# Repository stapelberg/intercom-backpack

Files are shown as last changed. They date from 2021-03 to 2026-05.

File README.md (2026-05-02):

# Intercom MQTT Backpack

See https://michael.stapelberg.ch/posts/2021-03-13-smart-intercom-backpack/

## Components

### tinypico-mqtt-nuki/

ESP32 (TinyPICO) firmware that bridges the BTicino SCS bus and a Nuki Opener
to MQTT. Listens for door-station ring telegrams, drives the Nuki opener (or
the local relay), and exposes everything as MQTT topics.

#### MQTT topics

Published by the doorbell:

| Topic | Payload | Notes |
|---|---|---|
| `doorbell/status` | `online` / `offline` | retained, LWT |
| `doorbell/heartbeat` | `{"uptime_s":N,"rssi":N,"silent":bool}` | every 60 s |
| `doorbell/events/scs` | hex-encoded 7-byte SCS telegram (e.g. `a8 91 03 60 …`) | every detected frame |
| `doorbell/events/ring` | `house` or `floor` | one per ring event |
| `doorbell/silent_state` | `on` / `off` | retained, doorbell echo |
| `doorbell/debug/suppressed` | `nukiRing` / `floorRingNuki` | when silent suppressed |
| `doorbell/debug/nukiring` | `ring` | after Nuki yellow pulse |
| `doorbell/debug/doorunlock` | `doorunlock` | after relay pulse |
| `doorbell/debug/floorring` | `low` / `high` | after floor ring debounce |

Subscribed by the doorbell (set from anywhere on the LAN):

| Topic | Payload | Effect |
|---|---|---|
| `doorbell/cmd/unlock` | any | pulses the door-open relay (500 ms) |
| `doorbell/debug/cmd/ring` | any | simulates a ring (drives Nuki yellow) |
| `doorbell/silent` | `on` / `off` (retained) | suppresses Nuki auto-trigger; rings still observable on `events/ring` |

`doorbell/silent` should be published with the retained flag so the state
survives doorbell reboots:

```
mosquitto_pub -h mqtt.lan -t doorbell/silent -r -m on
```

#### Build and flash on NixOS

Pinned to esp32:esp32 2.0.17, PubSubClient 2.8, TinyPICO Helper Library 1.3.0.

One-time bootstrap (downloads the ESP32 core and the two libraries into
`~/.arduino15` and `~/Arduino`):

```bash
nix-shell -p arduino-cli --run '
  arduino-cli config init --overwrite
  arduino-cli config add board_manager.additional_urls \
    https://espressif.github.io/arduino-esp32/package_esp32_index.json
  arduino-cli core update-index
  arduino-cli core install esp32:esp32@2.0.17
  arduino-cli lib install "PubSubClient@2.8"
  arduino-cli lib install "TinyPICO Helper Library@1.3.0"
'
```

esp32 2.0.17 ships an `esptool.py` whose shebang is `#!/usr/bin/env python`
(not `python3`) and that imports `pyserial`. NixOS provides neither in the
default PATH, so build/flash needs both `arduino-cli` and a
`python3.withPackages [pyserial]` plus a one-line `python` shim:

```bash
mkdir -p ~/.local/share/arduino-pyshim
ln -sf "$(command -v python3)" ~/.local/share/arduino-pyshim/python
```

Build (verify):

```bash
nix-shell -p arduino-cli 'python3.withPackages (ps: [ps.pyserial])' --run '
  PATH=~/.local/share/arduino-pyshim:$PATH \
    arduino-cli compile --fqbn esp32:esp32:tinypico ./tinypico-mqtt-nuki
'
```

Expected: ~760 KB sketch (58 % of program flash), ~45 KB globals (13 % of
DRAM), no warnings.

Flash (TinyPICO usually shows up as `/dev/ttyUSBN` via its CP2104 USB-UART
bridge — check `ls /dev/serial/by-id/`):

```bash
nix-shell -p arduino-cli 'python3.withPackages (ps: [ps.pyserial])' --run '
  PATH=~/.local/share/arduino-pyshim:$PATH \
    arduino-cli upload -p /dev/ttyUSB0 --fqbn esp32:esp32:tinypico ./tinypico-mqtt-nuki
'
```

Access to `/dev/ttyUSB*` requires the user to be in the `dialout` group.

### qt-py-scs2uart/

Adafruit QT Py firmware that decodes SCS bus signals and forwards them as
9600-baud UART to whatever sits behind it (in this repo, the TinyPICO above).
Same arduino-cli mechanics as the tinypico build, different board package
(this one has not been re-validated on NixOS in 2026):

```bash
nix-shell -p arduino-cli --run '
  arduino-cli config add board_manager.additional_urls \
    https://www.adafruit.com/package_adafruit_index.json
  arduino-cli core update-index
  arduino-cli core install adafruit:samd
  arduino-cli compile --fqbn adafruit:samd:adafruit_qtpy_m0 ./qt-py-scs2uart
'
```

### kicad-backpack/

A board that is mounted onto the [Adafruit QT
Py](https://www.adafruit.com/product/4600) (hence “backpack”) and adds 5V/3.3V
conversion for interfacing with a BTicino intercom unit (5V).

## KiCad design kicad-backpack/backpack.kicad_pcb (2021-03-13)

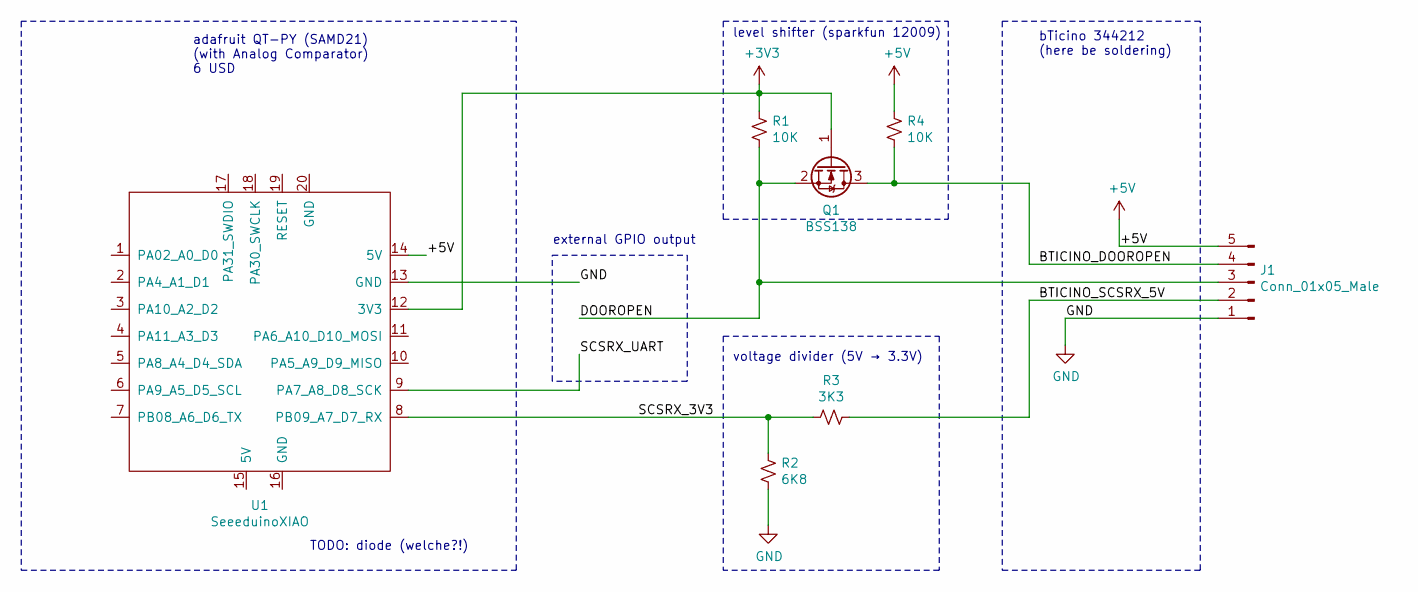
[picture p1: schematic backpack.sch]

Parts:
J1: Conn_01x05_Male; PinHeader_1x05_P2.54mm_Horizontal
Q1: BSS138; SOT-23
R1, R4: 10K; R_0603_1608Metric_Pad0.98x0.95mm_HandSolder
R2: 6K8; R_0603_1608Metric_Pad0.98x0.95mm_HandSolder
R3: 3K3; R_0603_1608Metric_Pad0.98x0.95mm_HandSolder
U1: SeeeduinoXIAO; Seeeduino XIAO-MOUDLE14P-2.54-21X17.8MM

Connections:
+3V3: Q1.1 (G), R1.1, U1.12 (3V3)
+5V: J1.5, R4.1, U1.14 (5V)
/BTICINO_DOOROPEN: J1.4, Q1.3 (D), R4.2
/BTICINO_SCSRX_5V: J1.2, R3.1
/DOOROPEN: J1.3, Q1.2 (S), R1.2
/SCSRX_3V3: R2.1, R3.2, U1.8 (PB09_A7_D7_RX)
/SCSRX_UART: U1.9 (PA7_A8_D8_SCK)
GND: J1.1, R2.2, U1.13 (GND)

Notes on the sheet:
adafruit QT-PY (SAMD21) (with Analog Comparator) 6 USD
voltage divider (5V → 3.3V)
level shifter (sparkfun 12009)
bTicino 344212 (here be soldering)
external GPIO output
TODO: diode (welche?!)

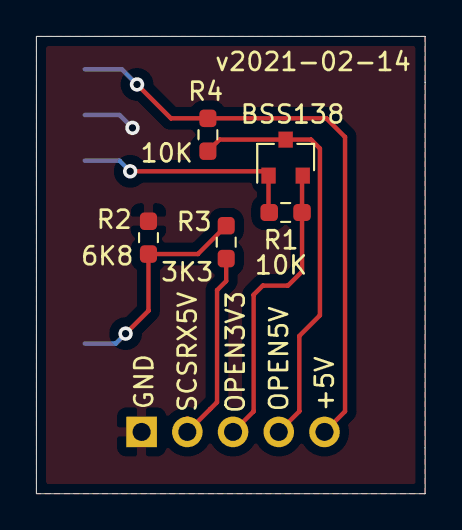
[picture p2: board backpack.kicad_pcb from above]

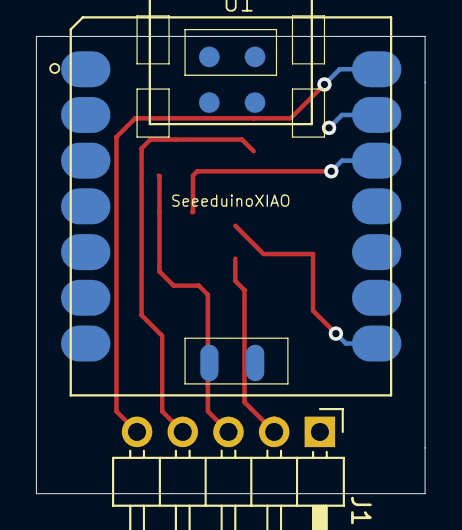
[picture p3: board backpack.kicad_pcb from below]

Board: 2 copper layers, 21.6 x 25.4 mm, 7 parts (2 on the bottom side), 7 nets.

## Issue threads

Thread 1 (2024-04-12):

ESP Biticino scs bus

MattWestb, 2024-04-12:
Have you thinking porting the code to ESPHome ?
I have one device and 32 neighbors and like getting it easy integrated in HA but dont have the code experience for do it only the hardware hacking im good on (like Zigbee hardware and so on).
Thanks in advance.

MW

stapelberg, 2024-04-12:
I have no plans to port this code to ESPhome.

If you don’t have the experience, I suggest finding a local makerspace, hackerspace or fablab. The community there will be able to help you with such electronics projects.

MattWestb, 2024-04-12:
Servus Michael.

Thanks for replaying. I continue looking around and see if i can finding some usebal code then you have getting all the hardware in place (I think i have taken the power on the cap if its is 5V and not on the small pins on one IC).

Mvh Mattias W

Closed 2024-04-12.

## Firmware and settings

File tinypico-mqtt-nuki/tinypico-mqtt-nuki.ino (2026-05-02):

#include <PubSubClient.h>
#include <TinyPICO.h>
#include <WiFi.h>
#include <driver/adc.h>
#include <driver/dac.h>

#include "scsfilter.h"

#define GPIO_DOOR_OPEN 27
#define GPIO_NUKI_YELLOW 14
#define GPIO_NUKI_BLUE 15
#define GPIO_FLOOR_RING 4

void nukiRing(void *pvParameters);

WiFiClient wificlient;
PubSubClient client(wificlient);

// PubSubClient is not thread-safe. All client.publish/connect/loop calls go
// through this mutex; publishers from other tasks use mqttPublish below.
static SemaphoreHandle_t xMqttMutex = NULL;

static bool mqttPublish(const char *topic, const char *payload,
                        bool retained = false) {
  if (xSemaphoreTake(xMqttMutex, pdMS_TO_TICKS(200)) != pdTRUE) return false;
  bool ok = client.publish(topic, payload, retained);
  xSemaphoreGive(xMqttMutex);
  return ok;
}

// silentMode suppresses the nuki opener auto-trigger from ring events.
// Toggled via retained MQTT topic doorbell/silent ("on"/"off").
static volatile bool silentMode = false;

// TODO: give this a constructor or something
scsfilter sf;

static bool ignore_scs_telegrams = false;
static uint8_t ignore_scs_checksum;
static TimerHandle_t xQuietTimer;

void scsquietnow(void *pvParameters) {
  ignore_scs_telegrams = false;
  Serial.println("timer fire, messages okay again");
  xTimerDelete(xQuietTimer, 10);
  xQuietTimer = NULL;
}

void taskscsprocess(void *pvParameters) {
  for (;;) {
    if (Serial2.available() == 0) {
      vTaskDelay(pdMS_TO_TICKS(10));
      continue;
    }

    byte incomingByte = Serial2.read();
    Serial.printf("[core %d] SCSRX: ", xPortGetCoreID());
    Serial.println(incomingByte, HEX);

    // We store the checksum of telegrams to ignore, so that different
    // messages are not accidentally ignored by the quiet timer.
    //
    // This can happen when e.g. the mailman rings the neighbor first, and then
    // my doorbell: the ring signal for my doorbell was ignored while the bus
    // was still active from delivering the neighbor ring signal.
    const bool ignore_this_telegram = ignore_scs_telegrams;
    const uint8_t ignore_this_telegram_checksum = ignore_scs_checksum;

    if (xQuietTimer != NULL) {
      xTimerReset(xQuietTimer, 10);
    }

    // feed this byte into the SCS decoder:
    sf_WriteByte(&sf, incomingByte);

    if (!sf_completeAndValid(&sf)) {
      continue;
    }

    const uint8_t checksum = sf.tbuf[5];
    Serial.printf("complete SCS telegram detected, checksum %x\n", checksum);

    if (ignore_this_telegram && ignore_this_telegram_checksum == checksum) {
      Serial.println("ignoring retransmission");
      continue;
    }

    {
      // Ignore the SCS bus retransmissions by waiting until the bus quiets
      // down: this timer gets restarted on every received byte.
      ignore_scs_telegrams = true;
      ignore_scs_checksum = checksum;
      xQuietTimer =
          xTimerCreate("scsquiet", // human readable text name for debugging
                       pdMS_TO_TICKS(50), // xTimerPeriod (in ticks)
                       pdFALSE,           // uxAutoReload (or one-shot)
                       NULL,              // timer id
                       scsquietnow);      // callback function
      if (xQuietTimer != NULL) {
        xTimerStart(xQuietTimer, 0);
        Serial.println("timer start");
      }
    }

    // Publish an MQTT message for each SCS telegram, hex-encoded so bytes
    // >=0x80 survive UTF-8-decoding MQTT subscribers (mosquitto_sub -v etc).
    char hex[3 * telegramLen];
    snprintf(hex, sizeof(hex),
             "%02x %02x %02x %02x %02x %02x %02x",
             sf.tbuf[0], sf.tbuf[1], sf.tbuf[2], sf.tbuf[3],
             sf.tbuf[4], sf.tbuf[5], sf.tbuf[6]);
    mqttPublish("doorbell/events/scs", hex);
    Serial.println("mqtt publish");

    if (sf_ringForApartment(&sf) == 3) {
      mqttPublish("doorbell/events/ring", "house");
      Serial.println("ring detected, triggering nuki opener");
      xTaskCreatePinnedToCore(nukiRing, "nukiRing", 4096, NULL, 1, NULL,
                              PRO_CPU_NUM);
    }
  }
}

// --------------------------------------------------------------------------------

void connectToWiFi(void) {
  Serial.println("WiFi: configuring");
  WiFi.mode(WIFI_STA);
  // required to set hostname properly:
  // https://github.com/espressif/arduino-esp32/issues/3438#issuecomment-721428310
  WiFi.config(INADDR_NONE, INADDR_NONE, INADDR_NONE, INADDR_NONE);
  WiFi.setHostname("doorbelltp");
  WiFi.begin("secret", "secret");
  while (WiFi.status() != WL_CONNECTED) {
    Serial.println("WiFi: connecting...");
    delay(100);
  }
  Serial.print("WiFi: connected: mac=");
  Serial.print(WiFi.macAddress());
  Serial.print(" ip=");
  Serial.print(WiFi.localIP());
  Serial.println("");
}

// --------------------------------------------------------------------------------

void nukiRing(void *pvParameters) {
  Serial.printf("[core %d] nukiRing\n", xPortGetCoreID());
  if (silentMode) {
    mqttPublish("doorbell/debug/suppressed", "nukiRing");
    vTaskDelete(NULL);
    return;
  }
  digitalWrite(GPIO_NUKI_YELLOW, HIGH);
  vTaskDelay(pdMS_TO_TICKS(1000));
  digitalWrite(GPIO_NUKI_YELLOW, LOW);
  mqttPublish("doorbell/debug/nukiring", "ring");
  vTaskDelete(NULL);
}

void doorUnlock(void *pvParameters) {
  Serial.printf("[core %d] doorUnlock\n", xPortGetCoreID());
  digitalWrite(GPIO_DOOR_OPEN, LOW);
  vTaskDelay(pdMS_TO_TICKS(500));
  digitalWrite(GPIO_DOOR_OPEN, HIGH);
  mqttPublish("doorbell/debug/doorunlock", "doorunlock");
  vTaskDelete(NULL);
}

SemaphoreHandle_t xNukiOpenSemaphore = NULL;

// IRAM_ATTR: all interrupt service routines must go into the internal SRAM:
// https://docs.espressif.com/projects/esp-idf/en/latest/esp32/api-guides/general-notes.html#iram-instruction-ram
void IRAM_ATTR nukiOpen() { xSemaphoreGiveFromISR(xNukiOpenSemaphore, NULL); }

// setupnuki0 runs the wakeup loop. It is pinned to PRO_CPU so the handler
// task is on the same core as the original interrupt-handling design.
void setupnuki0(void *pvParameters) {
  for (;;) {
    if (xSemaphoreTake(xNukiOpenSemaphore, portMAX_DELAY) != pdTRUE) {
      continue;
    }

    // TODO: where do these come from? unclear.
    if (digitalRead(GPIO_NUKI_BLUE) != LOW) {
      Serial.printf("ignoring spurious nukiOpen\n");
      continue;
    }

    xTaskCreatePinnedToCore(doorUnlock, "doorUnlock", 4096, NULL, 1, NULL,
                            PRO_CPU_NUM);
  }
}

void setupnuki(void) {
  xNukiOpenSemaphore = xSemaphoreCreateBinary();

  // pin GPIO_NUKI_YELLOW: connected to nuki opener yellow cable (RING)
  pinMode(GPIO_NUKI_YELLOW, OUTPUT);
  digitalWrite(GPIO_NUKI_YELLOW, LOW);

  // pin GPIO_NUKI_BLUE: connected to nuki opener blue cable (OPEN)
  pinMode(GPIO_NUKI_BLUE, INPUT_PULLUP);
  // attachInterrupt must run before the loop tasks start: arduino-esp32 2.x
  // crashes (LoadProhibited in esp_intr_get_cpu) if two tasks race to call
  // attachInterrupt for the first time. setup() serializes it.
  attachInterrupt(GPIO_NUKI_BLUE, nukiOpen, FALLING);
  xTaskCreatePinnedToCore(setupnuki0, "setupnuki0", 4096, NULL, 1, NULL,
                          PRO_CPU_NUM);
}

// --------------------------------------------------------------------------------

void floorRingNuki(void *pvParameters) {
  Serial.printf("[core %d] floorRing\n", xPortGetCoreID());
  mqttPublish("doorbell/events/ring", "floor");
  if (silentMode) {
    mqttPublish("doorbell/debug/suppressed", "floorRingNuki");
    vTaskDelete(NULL);
    return;
  }
  const byte state = digitalRead(GPIO_FLOOR_RING);
  digitalWrite(GPIO_NUKI_YELLOW, HIGH);
  vTaskDelay(pdMS_TO_TICKS(1000));
  digitalWrite(GPIO_NUKI_YELLOW, LOW);
  mqttPublish("doorbell/debug/floorring", state == LOW ? "low" : "high");
  vTaskDelete(NULL);
}

SemaphoreHandle_t xFloorOpenSemaphore = NULL;

// IRAM_ATTR: all interrupt service routines must go into the internal SRAM:
// https://docs.espressif.com/projects/esp-idf/en/latest/esp32/api-guides/general-notes.html#iram-instruction-ram
void IRAM_ATTR floorRing() { xSemaphoreGiveFromISR(xFloorOpenSemaphore, NULL); }

static byte floorRingState = LOW;
static unsigned long lastFloorRing;

// setupfloor0 runs the wakeup loop. attachInterrupt was already called from
// setupfloor() on the main task to avoid the arduino-esp32 2.x race.
void setupfloor0(void *pvParameters) {
  for (;;) {
    if (xSemaphoreTake(xFloorOpenSemaphore, portMAX_DELAY) != pdTRUE) {
      continue;
    }
    if (floorRingState == LOW && (millis() - lastFloorRing) < 1000) {
      continue; // debounce by waiting it out
    }

    const byte state = digitalRead(GPIO_FLOOR_RING);
    Serial.printf("GPIO_FLOOR_RING was %s\n",
                  floorRingState == LOW ? "low" : "high");
    Serial.printf("GPIO_FLOOR_RING is %s\n", state == LOW ? "low" : "high");
    Serial.printf("\n");
    if (floorRingState == LOW && state == HIGH) {
      // debounce: wait if HIGH after 100ms still
      vTaskDelay(pdMS_TO_TICKS(100));
      const byte debouncedstate = digitalRead(GPIO_FLOOR_RING);
      Serial.printf("debouncedstate is %s\n",
                    debouncedstate == LOW ? "low" : "high");
      if (debouncedstate != HIGH) {
        continue; // too short a press, or spurious
      }
      xTaskCreatePinnedToCore(floorRingNuki, "floorRingNuki", 4096, NULL, 1,
                              NULL, PRO_CPU_NUM);
      lastFloorRing = millis();
    }
    floorRingState = state;
  }
}

void setupfloor(void) {
  xFloorOpenSemaphore = xSemaphoreCreateBinary();

  // pin GPIO_FLOOR_RING: connected to floor ring signal
  pinMode(GPIO_FLOOR_RING, INPUT_PULLDOWN);
  attachInterrupt(GPIO_FLOOR_RING, floorRing, RISING);
  xTaskCreatePinnedToCore(setupfloor0, "setupfloor0", 4096, NULL, 1, NULL,
                          PRO_CPU_NUM);
}

// --------------------------------------------------------------------------------

void callback(char *topic, byte *payload, unsigned int length) {
  Serial.print("Message arrived [");
  Serial.print(topic);
  Serial.print("] ");
  for (int i = 0; i < length; i++) {
    Serial.print((char)payload[i]);
  }
  Serial.println();

  if (strcmp(topic, "doorbell/cmd/unlock") == 0) {
    xTaskCreatePinnedToCore(doorUnlock, "doorUnlock", 4096, NULL, 1, NULL,
                            PRO_CPU_NUM);
  }

  if (strcmp(topic, "doorbell/debug/cmd/ring") == 0) {
    xTaskCreatePinnedToCore(nukiRing, "nukiRing", 4096, NULL, 1, NULL,
                            PRO_CPU_NUM);
  }

  if (strcmp(topic, "doorbell/silent") == 0) {
    // payload is not NUL-terminated; compare with length.
    bool newMode =
        (length == 2 && payload[0] == 'o' && payload[1] == 'n');
    silentMode = newMode;
    Serial.printf("silentMode = %d\n", newMode ? 1 : 0);
    // We are inside client.loop(), which taskmqtt called while holding
    // xMqttMutex — use the raw publish (not mqttPublish) to avoid the
    // wrapper's redundant take-with-timeout.
    client.publish("doorbell/silent_state", newMode ? "on" : "off",
                   /* retained */ true);
  }
}

void taskmqtt(void *pvParameters) {
  for (;;) {
    xSemaphoreTake(xMqttMutex, portMAX_DELAY);
    if (!client.connected()) {
      // TODO: do we need a timeout here? does client.connect only block the
      // taskmqtt FreeRTOS task, or all FreeRTOS tasks on this core?
      client.connect("doorbelltp",     // clientid
                     "doorbell/status", // willTopic
                     0,                 // willQos
                     true,              // willRetain
                     "offline");        // willMessage
      client.publish("doorbell/status", "online", /* retained */ true);
      client.subscribe("doorbell/cmd/unlock");
      client.subscribe("doorbell/debug/cmd/ring");
      client.subscribe("doorbell/silent");
    }

    // Poll PubSubClient for new messages and invoke the callback.
    // Should be called as infrequent as one is willing to delay
    // reacting to MQTT messages.
    // Should not be called too frequently to avoid strain on
    // the network hardware:
    // https://github.com/knolleary/pubsubclient/issues/756#issuecomment-654335096
    client.loop();
    xSemaphoreGive(xMqttMutex);
    vTaskDelay(pdMS_TO_TICKS(100));
  }
}

// --------------------------------------------------------------------------------

void taskalive(void *pvParameters) {
  for (;;) {
    char buf[96];
    snprintf(buf, sizeof(buf),
             "{\"uptime_s\":%lu,\"rssi\":%d,\"silent\":%s}",
             (unsigned long)(millis() / 1000),
             (int)WiFi.RSSI(),
             silentMode ? "true" : "false");
    mqttPublish("doorbell/heartbeat", buf);
    vTaskDelay(pdMS_TO_TICKS(60000));
  }
}

// --------------------------------------------------------------------------------

void taskreconnect(void *pvParameters) {
  for (;;) {
    if (WiFi.status() != WL_CONNECTED) {
      Serial.printf("reconnecting to WiFi\n");
      connectToWiFi();
    }
    vTaskDelay(pdMS_TO_TICKS(60 * 1000));
  }
}

// --------------------------------------------------------------------------------

TinyPICO tp = TinyPICO();

void setup() {
  // Turn on Power LED:
  tp.DotStar_SetPixelColor(255, 128, 0);

  memset(&sf, '\0', sizeof(scsfilter));

  Serial.begin(115200);
  delay(1000);

  connectToWiFi();

  xMqttMutex = xSemaphoreCreateMutex();

  client.setServer("mqtt.lan", 1883);
  client.setCallback(callback);

  pinMode(GPIO_DOOR_OPEN, OUTPUT);
  digitalWrite(GPIO_DOOR_OPEN, HIGH);

  setupnuki();
  setupfloor();

  // setup UART2 (U2UXD) on GPIO pin 25 (RX)
  Serial2.begin(9600, SERIAL_8N1, 25, 26);

  // https://docs.espressif.com/projects/esp-idf/en/latest/esp32/api-guides/freertos-smp.html#scheduling
  // CPU 0 (PRO_CPU): protocol cpu
  // CPU 1 (APP_CPU): application cpu
  //
  // arduino-esp32 defaults to using APP_CPU for loop() and WiFi onEvent
  // callbacks. We leave loop() empty and use APP_CPU entirely for SCS ADC
  // conversion. Disable the IDLE-task watchdog on both cores: arduino-esp32
  // 2.x enforces it by default, and our PRO_CPU-pinned MQTT task can spend
  // multiple seconds inside PubSubClient::connect() during reconnects,
  // starving IDLE0 and tripping the watchdog.
  disableCore0WDT();
  disableCore1WDT();

  // Stack sizes were 2048 in the arduino-esp32 1.0.4 era, but 2.0.17's
  // runtime (attachInterrupt, WiFi/MQTT call paths) uses considerably
  // more stack — 2048 trips the stack canary in setupfloor0 within
  // seconds of WiFi connect. 4096 is the safe minimum; taskmqtt gets
  // 8192 since callback() runs on its stack during client.loop().
  xTaskCreatePinnedToCore(taskscsprocess, "SCS", 4096, NULL, 1, NULL,
                          PRO_CPU_NUM);

  xTaskCreatePinnedToCore(taskmqtt, "MQTT", 8192, NULL, 1, NULL, PRO_CPU_NUM);

  xTaskCreatePinnedToCore(taskalive, "Alive", 4096, NULL, 1, NULL, PRO_CPU_NUM);

  xTaskCreatePinnedToCore(taskreconnect, "reconnect", 4096, NULL, 1, NULL,
                          PRO_CPU_NUM);
}

// Arduino loop function unused in favor of FreeRTOS tasks.
// The ESP32 Arduino Board Support Package runs loop in a FreeRTOS task itself.
void loop() { vTaskDelay(pdMS_TO_TICKS(1000)); }

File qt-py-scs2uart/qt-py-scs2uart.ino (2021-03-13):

void setupADC();

void setup() {

  // SCSRX (from level shifter):
  pinMode(7, INPUT);

  // SCSRXUART (modified signal)
  pinMode(8, OUTPUT);
  digitalWrite(8, HIGH);

  setupADC();

  // turn off the NeoPixel for low power usage
  digitalWrite(12, LOW);
}

// Atmel AT11480: Analog Comparator Application Examples (18 pages)
// http://ww1.microchip.com/downloads/en/DeviceDoc/Atmel-42473-Analog-Comparator-Application-Examples_UserGuide_AT11480.pdf
// https://github.com/avrxml/asf/blob/master/sam0/applications/ac_examples/main.c

void setupADC() {
  PM->APBCMASK.reg |= PM_APBCMASK_AC;

  GCLK->CLKCTRL.reg =
      GCLK_CLKCTRL_CLKEN | GCLK_CLKCTRL_GEN_GCLK0 | GCLK_CLKCTRL_ID_AC_ANA;
  while (GCLK->STATUS.bit.SYNCBUSY)
    ;

  GCLK->CLKCTRL.reg =
      GCLK_CLKCTRL_CLKEN | GCLK_CLKCTRL_GEN_GCLK0 | GCLK_CLKCTRL_ID_AC_DIG;
  while (GCLK->STATUS.bit.SYNCBUSY)
    ;

  // Analog Comparator unterstützt als analog inputs nur:
  // - PA04: A2 (linke seite)
  // - PA05: A3 (linke seite)
  // - PA06: TX_A6 (linke seite)
  // - PA07: RX_A7 (rechte seite)

  // PA07, i.e. RX_A7, analog input
  {
    // Disable digital pin circuitry
    // gpio_set_pin_direction(PA05, GPIO_DIRECTION_OFF);
    PORT->Group[PORTA].DIRCLR.reg = (1 << 7); // turn off
    PORT->Group[PORTA].WRCONFIG.reg = PORT_WRCONFIG_WRPINCFG | (1 << 7);

    // gpio_set_pin_function(PA05, PINMUX_PA05B_AC_AIN1);
    // _gpio_set_pin_function(PA05, PINMUX_PA05B_AC_AIN1);
    PORT->Group[PORTA].PINCFG[7].bit.PMUXEN = 1;
    PORT->Group[PORTA].PMUX[7 >> 1].reg |= PORT_PMUX_PMUXO_B;
  }

  // Analog Comparator
  // ///////////////////////////////////////////////////////////////////////

  AC->COMPCTRL[0].reg =
      AC_COMPCTRL_HYST |        // Enable input hysteresis
      AC_COMPCTRL_OUT_OFF |     // Enable comparator output in asynchronous mode
      AC_COMPCTRL_MUXPOS_PIN3 | // Set the positive input multiplexer to AIN[3]
      AC_COMPCTRL_MUXNEG_VSCALE | // Set the negative input multiplexer to the
                                  // voltage scaler
      AC_COMPCTRL_SPEED_HIGH |    // Place the comparator into high speed mode
      AC_COMPCTRL_INTSEL_TOGGLE;
  while (AC->STATUSB.bit.SYNCBUSY)
    ; // Wait for synchronization

  AC->SCALER[0].reg = AC_SCALER_VALUE(
      39); // Set the negative input voltage scale to 2V
           // Vscale = Vdd * (VALUE + 1) / 64 = 3.3V * (39 + 1) / 64 = 2V

  AC->CTRLA.bit.ENABLE = 1; // Enable the analog comparator peripheral
  while (AC->STATUSB.bit.SYNCBUSY)
    ; // Wait for synchronization

  AC->COMPCTRL[0].bit.ENABLE = 1; // Enable the analog comparator channel 1
  while (AC->STATUSB.bit.SYNCBUSY)
    ; // Wait for synchronization

  // Enable interrupts
  AC->INTENSET.bit.COMP0 = 1;

  NVIC_SetPriority(AC_IRQn, 0); // highest priority
  NVIC_EnableIRQ(AC_IRQn);

  //	Serial.println("running");
}

// code example for SAMD21 analog comparator:
// https://forum.arduino.cc/index.php?topic=649060.msg4377953#msg4377953

volatile int state = -1; // handled

void AC_Handler(void) {
  // Acknowledge the interrupt:
  AC->INTFLAG.bit.COMP0 = 1;

  state = !(AC->STATUSA.bit.STATE0);
}

void loop() {
  // TODO: go into power save but allow for all interrupts
  if (state == -1) {
    return; // handled
  }
  if (state == HIGH) {
    delayMicroseconds(20);
    digitalWrite(8, HIGH);
    state = -1;
    return;
  }
  if (state == LOW) {
    digitalWrite(8, LOW);
    state = -1;
    return;
  }
}

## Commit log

2021-04-24 explicitly enable internal pull-down resistor
    Turns out that the opposite of INPUT_PULLUP isn’t INPUT, but INPUT_PULLDOWN.
2026-05-02 serialize MQTT with mutex, add LWT/heartbeat/silent mode
    PubSubClient is not thread-safe and was being called from four FreeRTOS
    tasks (taskscsprocess, nukiRing, doorUnlock, floorRingNuki) plus
    taskmqtt's loop()/connect(), which corrupted its TCP buffer and caused
    chronic reconnects. Wrap all access in xMqttMutex via mqttPublish().
    While here:
    - LWT: doorbell/status retained (online / offline-on-disconnect).
    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
2026-05-02 increase stack sizes to fix crashes
    [tinypico-mqtt-nuki.ino]
2026-05-02 attach interrupts early to fix crashes
    [tinypico-mqtt-nuki.ino]
2026-05-02 disable core 0 WDT to fix MQTT connection
    [tinypico-mqtt-nuki.ino]
2026-05-02 README: NixOS build/flash flow, document MQTT topic surface
    The 2021 Docker/debian:testing arduino-1.8.13 flow doesn't work cleanly
    on NixOS anymore (debian:testing has moved on, classic Arduino IDE is
    deprecated). Replace tinypico-mqtt-nuki/ instructions with the
    arduino-cli + nix-shell + python-shim flow validated end-to-end on x1x.
    Same recipe sketched (untested) for qt-py-scs2uart/.
    Also document the MQTT topic surface — events, commands, retained
    state — since it grew substantially with the silent-mode / heartbeat /
    LWT additions.
